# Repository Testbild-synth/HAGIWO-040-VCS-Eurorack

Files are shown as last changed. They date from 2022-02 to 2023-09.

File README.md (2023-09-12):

# HAGIWO-040-VCS-Eurorack
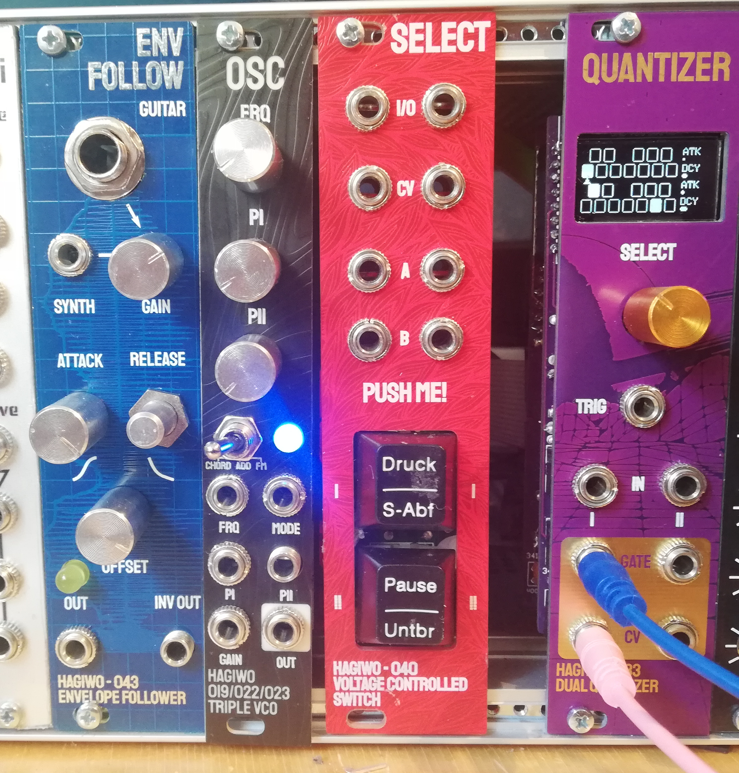
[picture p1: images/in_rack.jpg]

Through-hole PCB version of the [HAGIWO 040 Select Voltage controlled Switch Eurorack module](https://www.youtube.com/watch?v=aYyemBHd6mM) .
The module is basically built around an analog switch IC that allows you to direct one channel of a signal in one of two "output channels" depending on button presses or a control voltage.

I made the change to switch the IC to a DG211/DG411, since those are far more available to me. I also made the change to replace the threshold potentiometer in the front with a trimmer in the back, but also the trimmers are unique for each channel.

### STATUS: Now on version 4 with improved spacing on the panel and pcb. 

## PCB and Hardware

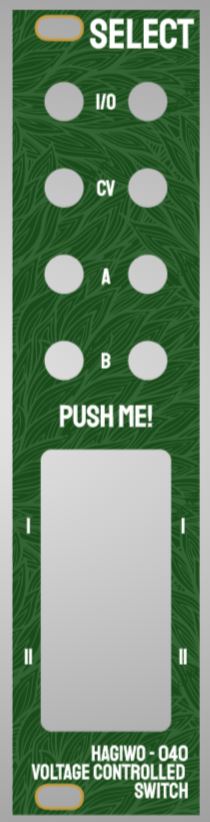
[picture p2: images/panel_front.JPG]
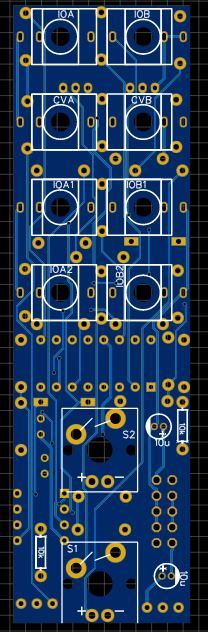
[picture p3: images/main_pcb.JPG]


You can find the schematic and BOM in the root folder. 
For the PCBs, the module has one circuit PCB and one panel PCB. You can order them on any common PCB manufacturing service, I used JLCPCB. Standard settings should be fine.

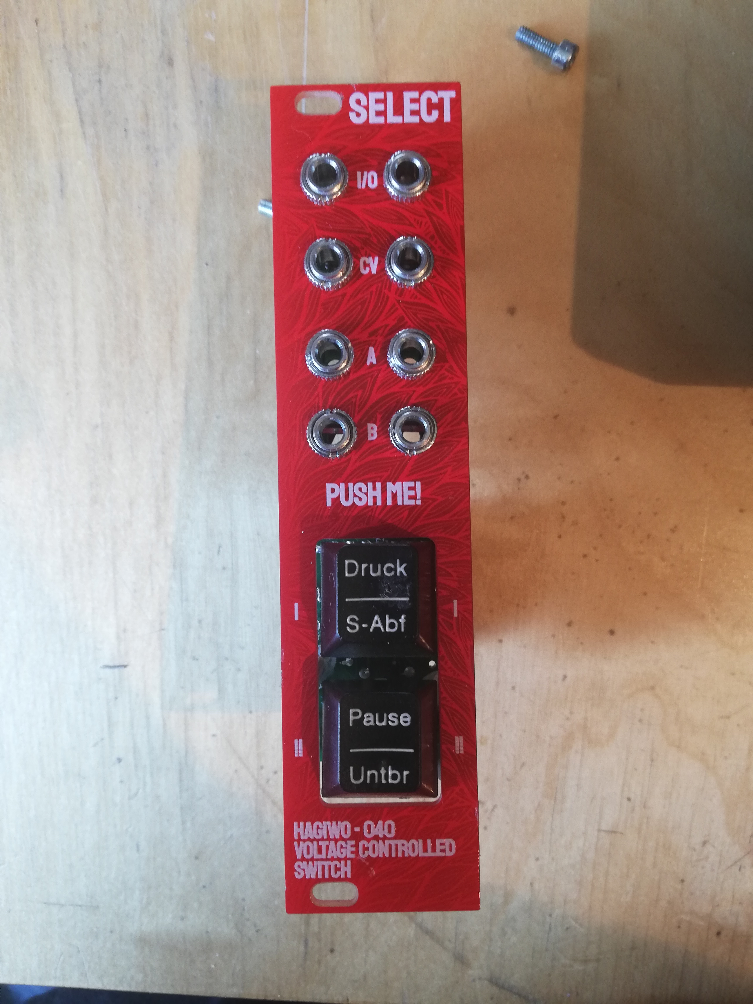
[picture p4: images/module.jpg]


Probably the only part that is a bit special about the BOM in this are the switches: I made the choice to switch the standard push switches HAGIWO uses to CHERRY MX switches.
They are bigger, sure, but they are also far more satisfying and everyone can [insert their favourite type](https://switchandclick.com/wp-content/uploads/2020/07/Cherry-MX-Switch-Guide-1-1024x679.webp), I vote for clicky blues! Make sure to get the "RGB" option which has space for the LED indicator. I got the wrong ones and had to kinda bend the bottom of mine to make the LED fit.

For the build, the PCB is very crowded since i tried to fit everything on one PCB. in former revisions there was a problem with jack spacing, but this has been solved. for earlier versions see the commit history.

## Tuning
The module has two trimpots which you can use to set the trigger voltage for each channel. The easiest way to set these imo is to feed it the voltage you want (say 2.5V) and then adjust the trimpot until the point where it barely triggers a channel change. I have mine set to different voltages (1V and 2V) so that I can feed the same lfo into both and get different timing from it, but do as you prefer!

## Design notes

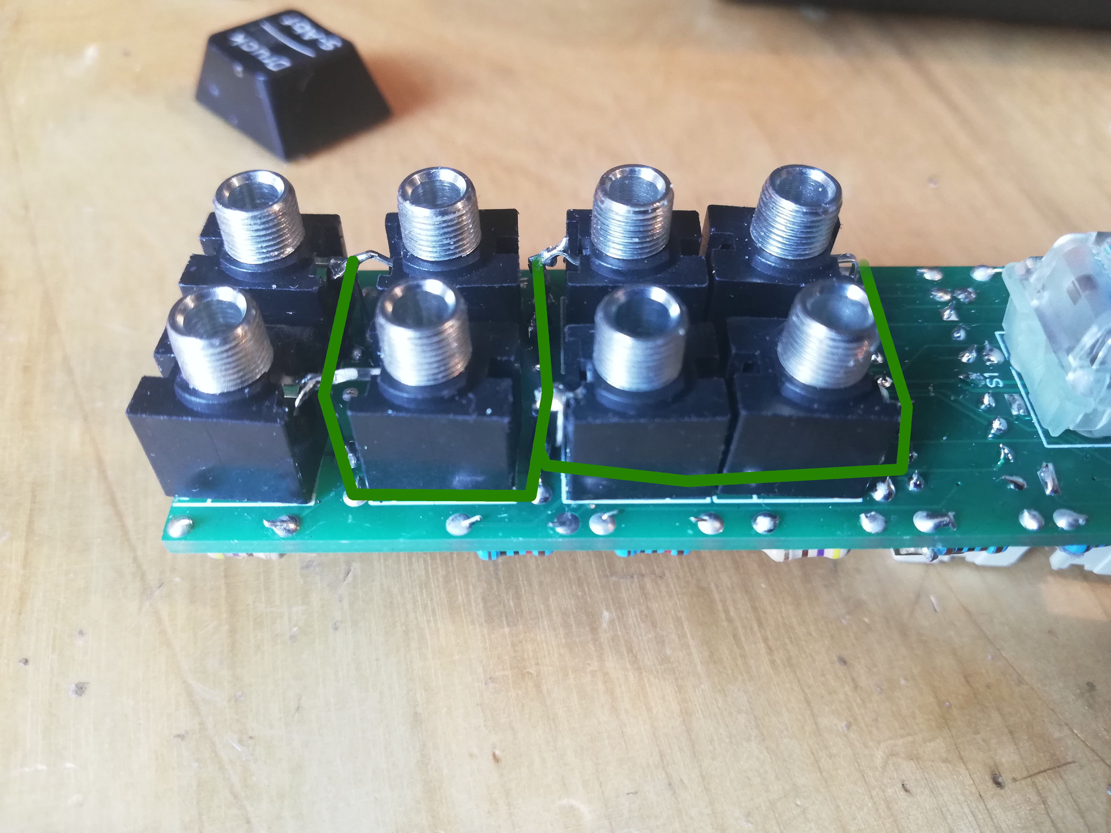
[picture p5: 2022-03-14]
images/jacks_grounds.jpg

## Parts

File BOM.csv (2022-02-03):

Name | Designator | Footprint | Quantity
100n | C1,C2 | RAD-0.1 | 2
10u | C3,C4 | CAP-D4.0×F1.5 | 2
1n4148 | D1,D2 | DO35-7 | 2
EURORACK POWER HEADER | EP1 | EURORACK_POWER_V2 | 1
Thonkiconn jack | J1-J8 | THONKICONN_1 | 8
470 | R1,R2,R5,R6,R7,R8 | R_AXIAL-0.3 | 6
1k | R3,R4,R9,R18 | R_AXIAL-0.3 | 4
10k | R10,R11,R12,R13,R14,R15,R16,R19,R20,R21,R22,R23,R24,R25 | R_AXIAL-0.3 | 14
33k | R17,R26 | R_AXIAL-0.3 | 2
CHERRY MX RGB SWITCH | S1,S2 | CHERRY-MX-LED | 2
10k trimpot | THRESH1,THRESH2 | TRIMPOT | 2
DG211CJ | U2 | DIP16 | 1
BC547 | U3,U4 | BC547 OH | 2
TL072 | U1 | DIP8 | 1

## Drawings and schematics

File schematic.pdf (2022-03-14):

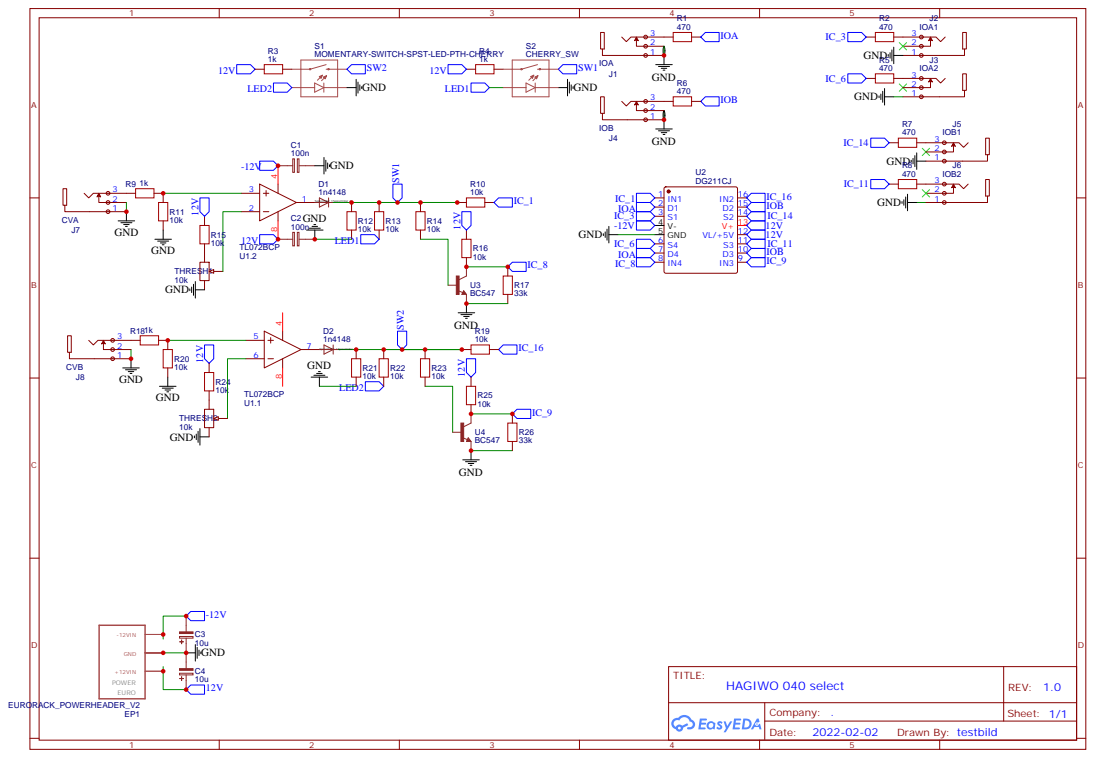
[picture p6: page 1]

MOMENTARY-SWITCH-SPST-LED-PTH-CHERRY

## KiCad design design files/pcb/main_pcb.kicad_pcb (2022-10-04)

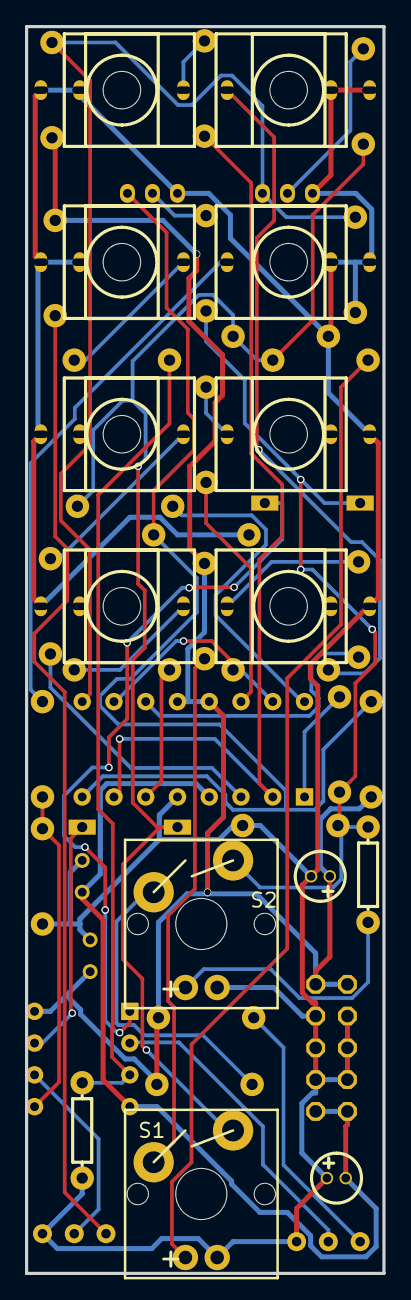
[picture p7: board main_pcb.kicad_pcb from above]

Board: 2 copper layers, 28.6 x 99.7 mm, 49 parts (0 on the bottom side), 37 nets.

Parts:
C1, C2: 100n; RAD-0.1
C3, C4: 10u; CAP-D4.0×F1.5
D1, D2: 1n4148; DO35-7
EP1: EURORACK_POWERHEADER_V2; EURORACK_POWER_V2
J1: IOA; THONKICONN_1
J2: IOA1; THONKICONN_1
J3: IOA2; THONKICONN_1
J4: IOB; THONKICONN_1
J5: IOB1; THONKICONN_1
J6: IOB2; THONKICONN_1
J7: CVA; THONKICONN_1
J8: CVB; THONKICONN_1
R1, R2, R5, R6, R7, R8: 470; R_AXIAL-0.3
R3, R4, R9, R18: 1k; R_AXIAL-0.3
R10, R11, R12, R13, R14, R15, R16, R19, R20, R21, R22, R23, R24, R25: 10k; R_AXIAL-0.3
R17, R26: 33k; R_AXIAL-0.3
S1: MOMENTARY-SWITCH-SPST-LED-PTH-CHERRY; CHERRY-MX-LED
S2: CHERRY_SW; CHERRY-MX-LED
THRESH1, THRESH2: 10k; TRIMPOT
U1: TL072BCP; DIP8
U2: DG211CJ; DIP16
U3, U4: BC547; BC547 OH

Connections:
12V: C2.1, C4.1, EP1.12, R3.1, R4.1, R15.1, R16.2, R24.1, R25.2, U1.8, U2.12, U2.13
-12V: C1.1, C3.2, EP1.-12, U1.4, U2.4
GND: C1.2, C2.2, C3.1, C4.2, EP1.GND0, EP1.GND1, EP1.GND2, EP1.GND3, EP1.GND4, EP1.GND5, J1.1, J1.2, J2.1, J3.1, J4.1, J4.2, J5.1, J6.1, J7.1, J7.2, J8.1, J8.2, R11.2, R12.2, R17.1, R20.2, R21.2, R26.1, S1.K, S2.K, THRESH1.3, THRESH2.3, U2.5, U3.3, U4.3
IC_1: R10.2, U2.1
IC_3: R2.1, U2.3
IC_6: R5.1, U2.6
IC_8: R16.1, R17.2, U2.8, U3.1
IC_9: R25.1, R26.2, U2.9, U4.1
IC_11: R8.1, U2.11
IC_14: R7.1, U2.14
IC_16: R19.2, U2.16
IOA: R1.2, U2.2, U2.7
IOB: R6.2, U2.10, U2.15
J1_3: J1.3, R1.1
J3_3: J3.3, R5.2
J5_3: J5.3, R7.2
J7_3: J7.3, R9.2
LED1: R13.2, S2.A
LED2: R22.2, S1.A
R2_2: J2.3, R2.2
R4_2: R4.2, S2.S1
R6_1: J4.3, R6.1
R8_2: J6.3, R8.2
R9_1: R9.1, R11.1, U1.3
R14_1: R14.1, U3.2
R18_2: J8.3, R18.2
R24_2: R24.2, THRESH2.1
S1_S1: R3.2, S1.S1
SW1: D1.C, R10.1, R12.1, R13.1, R14.2, S2.S2
SW2: D2.C, R19.1, R21.1, R22.1, R23.2, S1.S2
THRESH1_1: R15.2, THRESH1.1
U1_1: D1.A, U1.1
U1_2: THRESH1.2, U1.2
U1_5: R18.1, R20.1, U1.5
U1_6: THRESH2.2, U1.6
U1_7: D2.A, U1.7
U4_2: R23.1, U4.2

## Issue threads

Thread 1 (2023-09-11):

Panel gerbers is very large - possibly entire work surface

jacobsvensmark, 2023-09-11:
Hi

Very cool project. This is not necessarily a big issue (or an issue at all) but when I try to upload the gerbers for the panel to JLCPCB, it thinks that the PCB is huge - possibly it thinks the pcb is the entire KICAD work surface, not only the actual panel. I tried re-exporting gerbers from the kicad files, with the same result. Hope you have some insight! Thanks.

EDIT: Also, you write that it is designed for the "DG211/DG411" ICs, but write only the DG211 in the BOM. Could I use the DG411 as a drop in replacement, or would it take modification of sorts? What is the difference between using the two?

Testbild-synth, 2023-09-11:
Hi, I had some issues with this previously due to kicad project settings.
I'll fix it today and notify you once I have

jacobsvensmark ***@***.***> schrieb am Mo., 11. Sep. 2023,
09:08:

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

Testbild-synth, 2023-09-11:
fixed the pcb export, new file should work i checked in two different gerber viewers.
Regarding the chip, yes its a drop in replacement DG411 is a newer version that may have slightly different specs like a few nanoseconds different switch time. for our purposes it should not matter so use whichever one is easier to source for you

jacobsvensmark, 2023-09-12:
Nice, thanks!

Testbild-synth, 2023-09-12:
sorry, check again now idk what was wrong with my gitkraken yesterday

Closed 2023-09-11.

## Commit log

2022-02-03 created folder structure and uploaded panel design files
    [hagiwo_select.kicad_pcb]
2022-02-03 uploaded gerbers and design files for main pcb
    [main_pcb_v1.kicad_pcb]
2022-02-03 Added bom and schematic
    [BOM.csv]
2022-02-08 v2 pcb and panel, since jlc complained because of cutout dimensions
    [hagiwo_select.kicad_pcb, main_pcb_v1.kicad_pcb, main_pcb_v2.kicad_pcb]
2022-02-08 fixed an error with the panel pcb gerber
    [hagiwo_select.kicad_pcb]
2022-03-14 fixed a grounding issue with previous version
    [main_pcb_v2.kicad_pcb, main_pcb_v3.kicad_pcb]
2022-10-04 v4 better spacing
    [hagiwo_select.kicad_pcb, main_pcb.kicad_pcb, main_pcb_v3.kicad_pcb]
2023-09-11 fixed botched kicad export
    [hagiwo_select.kicad_pcb]
